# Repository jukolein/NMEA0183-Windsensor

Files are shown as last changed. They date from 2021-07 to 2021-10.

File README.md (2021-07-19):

# NMEA0183-Windsensor
A DIY-Windsensor capable of transmitting NMEA0813-sentences both wirelessly and over serial, based on an ESP8266. Build completely without custom turned parts.

sensor_komplett

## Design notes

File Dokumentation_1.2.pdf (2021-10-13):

# Windsensor III

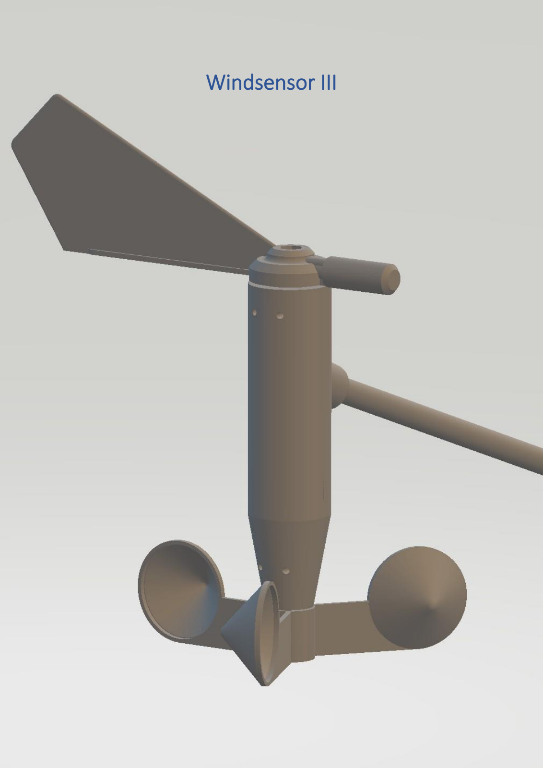
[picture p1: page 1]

## Inhaltsverzeichnis

### 1) Vorbemerkungen

Bei dem Windsensor III handelt es sich um einen einfach nachbaubaren Windsensor, der aus 3D-druckbaren Teilen und gut erhältlichen Standartkomponenten besteht. Durch den Verzicht auf Drehteile und eine einfach bedien- und anpassbare Software, an welcher keine Änderungen im Programmcode für die Integration in das eigene System benötigt werden, soll es möglichst vielen Interessierten ermöglicht werden, ihn nachzubauen.

Der Windsensor ist in der Lage Windrichtung und Windgeschwindigkeit zu messen und diese als NMEA0813-Datagramme auszugeben. Diese können danach entweder direkt über eine eigene grafische Oberfläche, welche zwar vom Windsensor bereitgestellt, jedoch vollständig auf dem Client verarbeitet wird, angezeigt oder an andere Geräte weitergegeben werden.

Diese Weitergaben kann entweder seriell, per UDP-Broadcast oder per TCP-Server geschehen. Hierfür gibt es zwei verschiedene Firmware-Versionen, eine für TCP und eine für UDP. Beide erzeugen auch immer die serielle Ausgabe.

In Ergänzung zu dieser Anleitung gibt es ein YouTube-Video, das die wichtigsten Punkte des Zusammenbaus des Windsensors noch einmal erklärt: https://www.youtube.com/watch?v=HD0CSuoLhfY

Die Firmware des Windsensors kann drahtlos aktualisiert werden, entweder über den WiFiManager oder über die OTA-Update-Funktion der Arduino-IDE

Das wichtigste in Kürze:

- Punkt des AS5600 muss von den Widerständen weg zeigen
- Widerstände der AS5600-Platine müssen unten sein
- Abgerundete Seite des Hallsensors muss nach unten zeigen
- Untere Header Leiste zum Flashen überbrücken
- Zur ersten Einrichtung mit dem WLAN „Windsensor“ verbinden, dann auf „192.168.4.1“
- Port 8080 für TCP und UDP
- „Windsensor_AP“ unter „192.168.4.1“ für Standalone

## 2) Stückliste

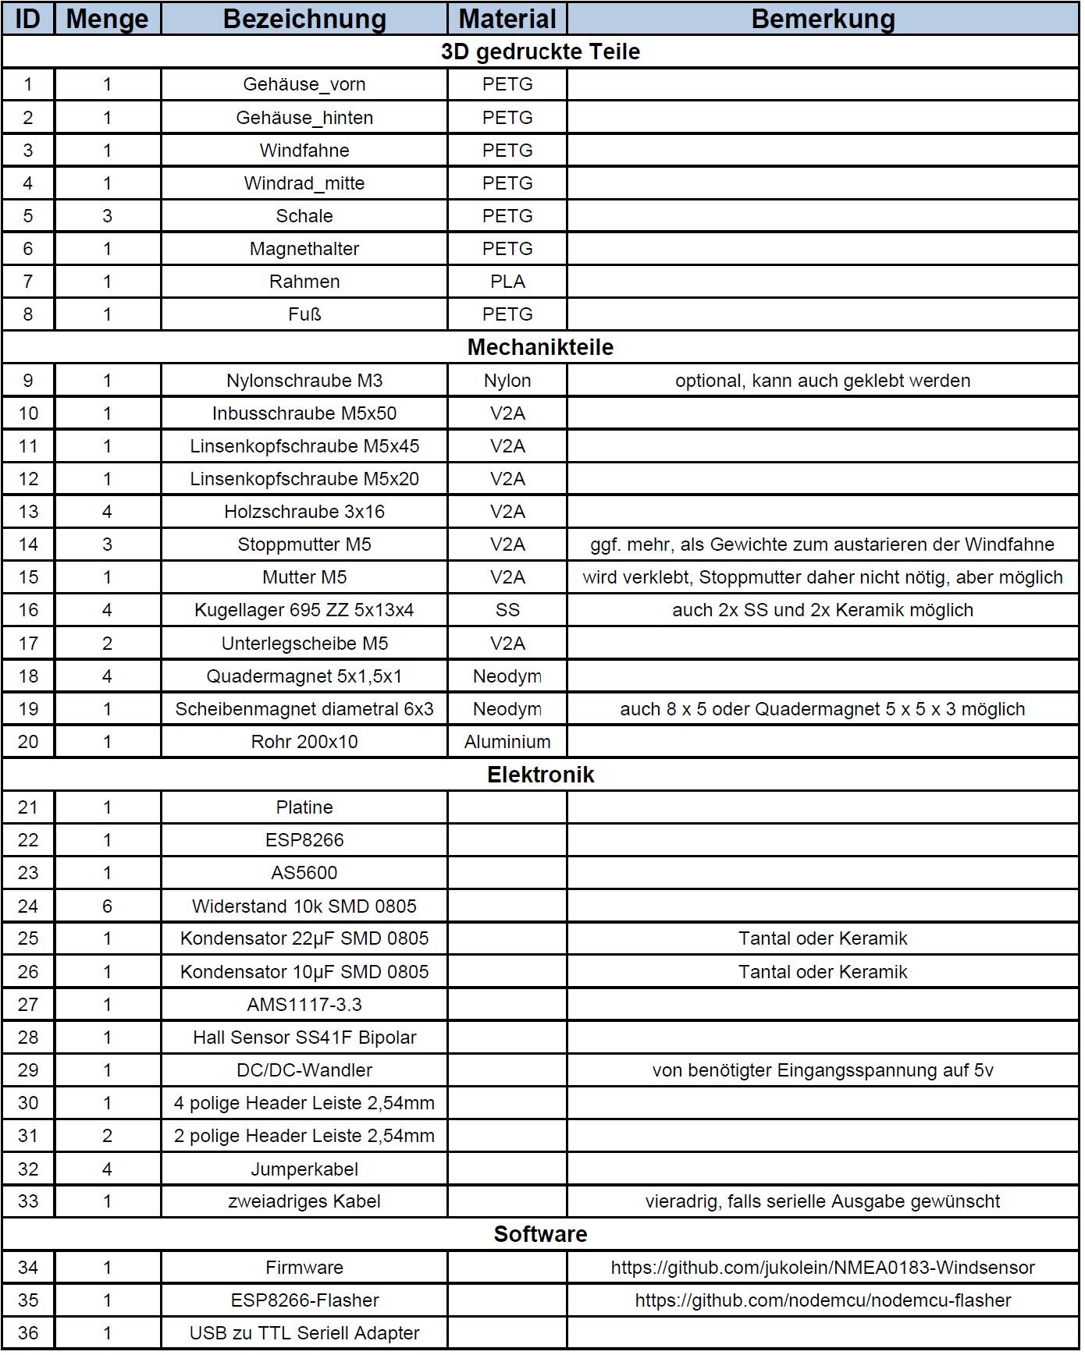
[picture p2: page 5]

## 3) Zusammenbau des Windsensors

Nachfolgend ist der Zusammenbau des Windsensors Schritt für Schritt dokumentiert. Zu Beginn eines jeden Abschnitts werden die nachfolgend benötigten Elemente aufgelistet. Die Nummern beziehen sich jeweils auf die ID der Stückliste.

### 3.1) Prüfen auf Vollständigkeit

In der nachfolgenden Abbildung fehlen der Fuß (8), die Nylonschraube (9), die Holzschrauben (13), das Alurohr (20), die elektronischen Bauteile 23 bis 26, der DC/DC-Wandler (29), die Kabel (32, 33) sowie der komplette Abschnitt Software (34 bis 36).

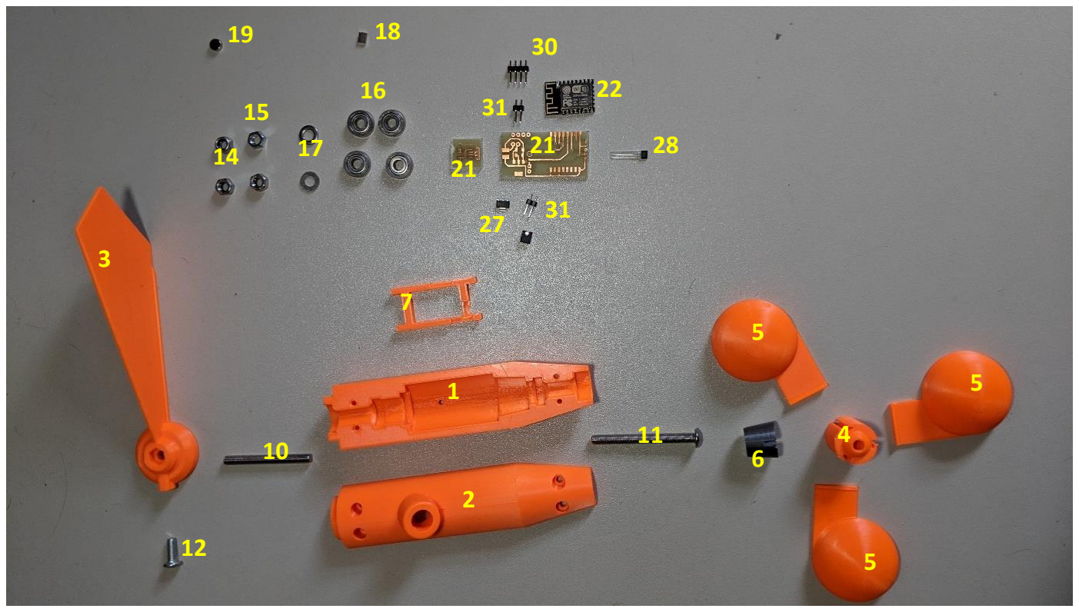
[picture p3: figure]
ine Formel ein

### 3.2) Vorbereiten des Gehäuses

Benötigte Teile: 1, 2

Um einen idealen Sitz der Kugellager zu gewährleisten ist es unter Umständen erforderlich, die Einlassungen für die Kugellager etwas nachzuarbeiten. Hierfür eignet sich etwa ein Schlitz-Schraubendreher.

### 3.3) Einkleben der Kugellager

Benötigte Teile: 1, 16

Dieser Punkt ist der wichtigste des gesamten Zusammenbaus. Sitzen die Kugellager auch nur leicht verkantet hat dies erhebliche Auswirkungen auf die Leichtgängigkeit und damit auch auf die Genauigkeit des Sensors. Es bietet sich an, die Kugellager in die obere Gehäusehälfte (1) einzukleben.

Zum Ausrichten kann die Imbus- oder Linsenkopfschraube (11/12) verwendet werden. Die Kugellager sitzen ideal, wenn die Schraube in vertikaler Position durch beide Kugellager hindurchfallen kann.

Sind die Kugellager richtig ausgerichtet, werden sie eingeklebt. Dies sollte bevorzugt mit einem restelastischen Kleber geschehen.

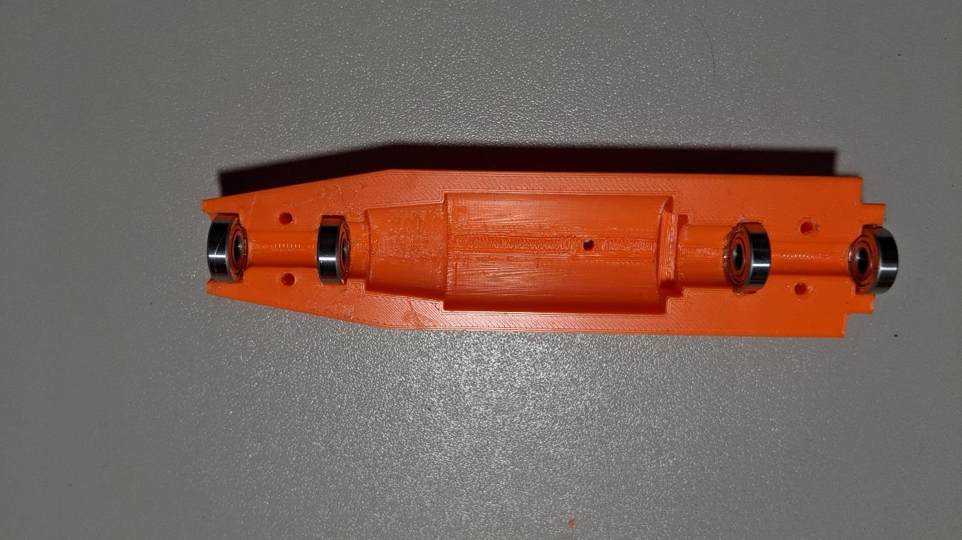
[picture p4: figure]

### 3.4) Vorbereiten des Magnethalters

Benötigte Teile: 6, 11, 14, 17

Die benötigten Teile werden wie folgt verbunden:

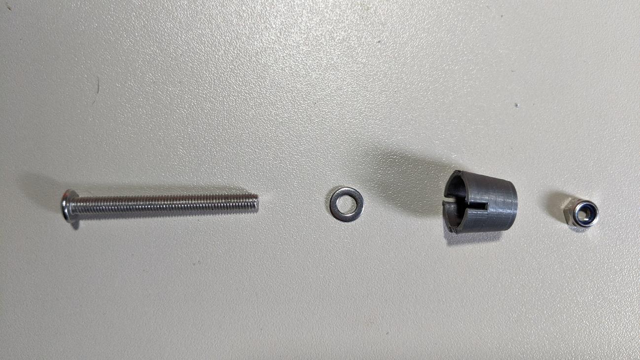
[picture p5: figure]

Die schmalere Seite der Stoppmutter muss hierbei vom Magnethalter weg zeigen.

### 3.5) Einbau der Schalen

Benötigte Teile: Alle aus Schritt 3) und 4), dazu 4, 5, 14

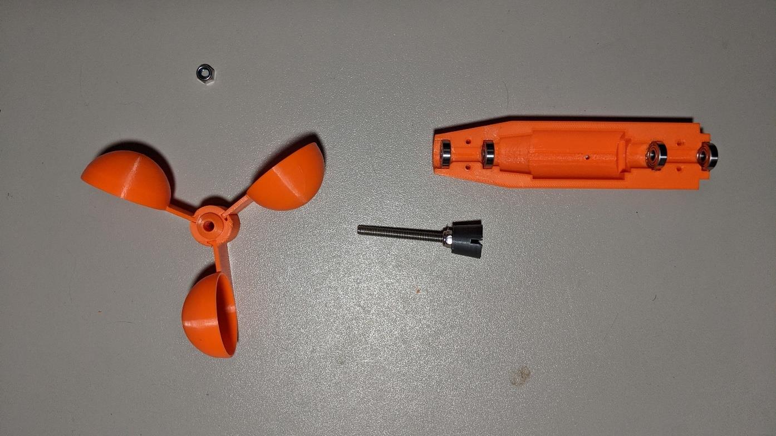
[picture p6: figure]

Zuerst die drei Schalen mit dem Windrad_mitte verbinden und mit Kleber sichern, selbst wenn sich die Teile beim Zusammenbau nur sehr schwer zusammenstecken lassen.

Anschließend den vorbereiteten Magnethalter vorsichtig durch die unteren Kugellager (die Seite, auf der sich das Gehäuse verjüngt) führen, das zusammengesteckte Windrad mit der Verjüngung in Richtung Gehäuse aufstecken und mit einer Stoppmutter sichern.

Auf freie Drehbarkeit des Magnethalters achten, besonders dann, wenn das Gehäuse mit dem zweiten Gehäuseteil geschlossen wird.

Ist die freie Drehbarkeit gewährleistet, kann die Schraube soweit angezogen werden, dass das Windrad nur noch minimales Spiel hat.

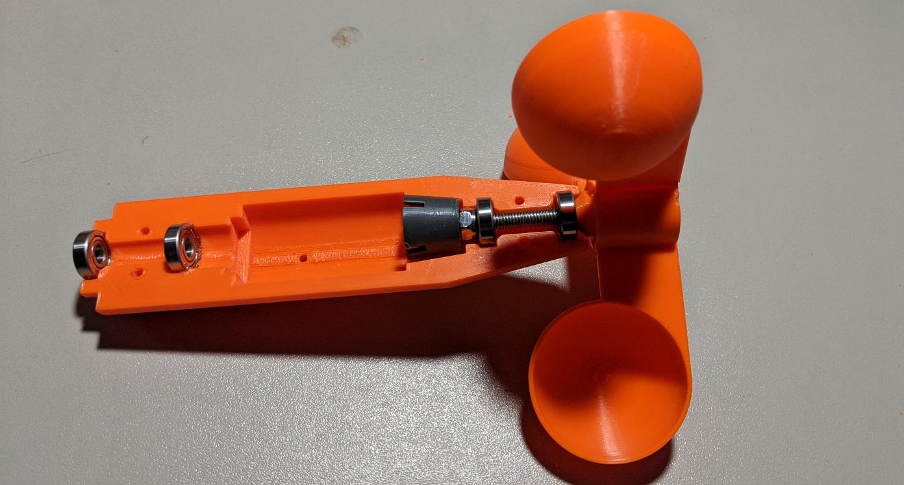
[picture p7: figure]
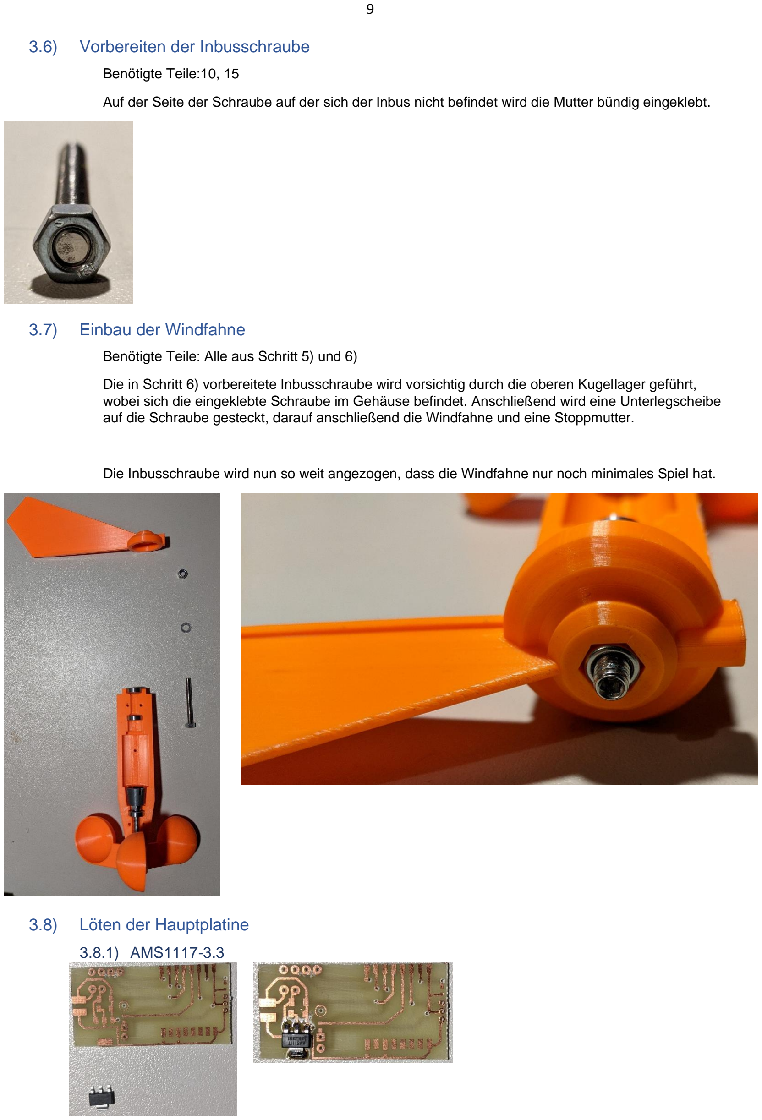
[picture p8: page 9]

### 3.6) Vorbereiten der Inbusschraube

Benötigte Teile:10, 15

Auf der Seite der Schraube auf der sich der Inbus nicht befindet wird die Mutter bündig eingeklebt.

### 3.7) Einbau der Windfahne

Benötigte Teile: Alle aus Schritt 5) und 6)

Die in Schritt 6) vorbereitete Inbusschraube wird vorsichtig durch die oberen Kugellager geführt, wobei sich die eingeklebte Schraube im Gehäuse befindet. Anschließend wird eine Unterlegscheibe auf die Schraube gesteckt, darauf anschließend die Windfahne und eine Stoppmutter.

Die Inbusschraube wird nun so weit angezogen, dass die Windfahne nur noch minimales Spiel hat.

### 3.8) Löten der Hauptplatine

3.8.1) AMS1117-3.3

3.8.2) Kondensatoren

Der 22 µF-Kondensator (25) befindet sich näher am AMS1117

3.8.3) ESP8266
3.8.4) Widerstände
3.8.5) Header Leisten
3.8.6) SS41F

Der bipolare Hallsensor muss mit der abgerundeten Seite nach unten eingesetzt werden.

### 3.8.7) Einpassen des Hallsensors

Die Füße des Hallsensors sind zu lang und müssen eingekürzt werden. Der abgerundete Teil des Sensors muss so positioniert sein, dass die Magneten des Magnethalters bei ihrer Umdrehung möglichst nah daran vorbei drehen. Der Sensor sollt somit im Besonderen nicht zu tief im Magnethalter positioniert werden.

### 3.9) Löten der AS5600-Platine

3.9.1) AS5600

Der Punkt auf dem AS5600 muss sich in der Ecke befinden, in der die zwei Kontaktflächen der Füßchen verbunden sind. Sprich: Gegenüber der zwei Widerstände, die im nächsten Schritt angelötet werden

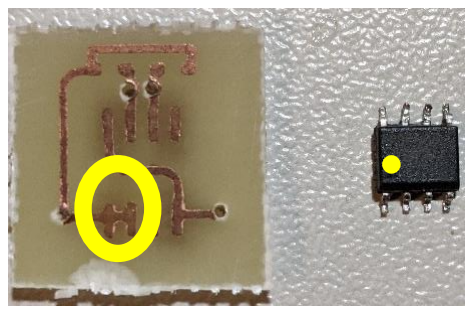
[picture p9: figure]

3.9.2) Widerstände
3.10) Verbinden der Platinen

Die kleine Platine wird mittig rechtwinklig auf die größere gelegt und beide Platinen mit Lötzinn so verbunden, dass jede der vier Lötflächen der großen Platine (zwei oben und zwei unten) mit genau einer Lötfläche der kleinen Platine kontakt hat. Beim Verbinden der beiden Platinen ist darauf zu achten, dass sich die beiden Widerstände der AS5600-Platine unterhalb der Hauptplatine befinden.

### 3.11) Einsetzen der Platine

Benötigte Teile: Alle aus Schritt 1.7) und 1.9), dazu 7

Um sicherzustellen, dass sich der AS5600 genau mittig zur Inbusschraube der Windfahne befindet, wird unter die fertige Platine ein Rahmen eingesetzt.

Anschließend wir der Hallsensor vorsichtig in den Magnethalter eingeführt und die Platine ausgerichtet

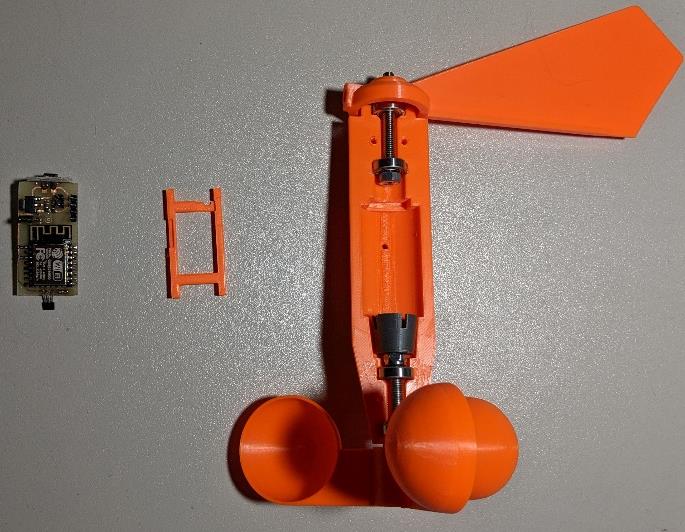
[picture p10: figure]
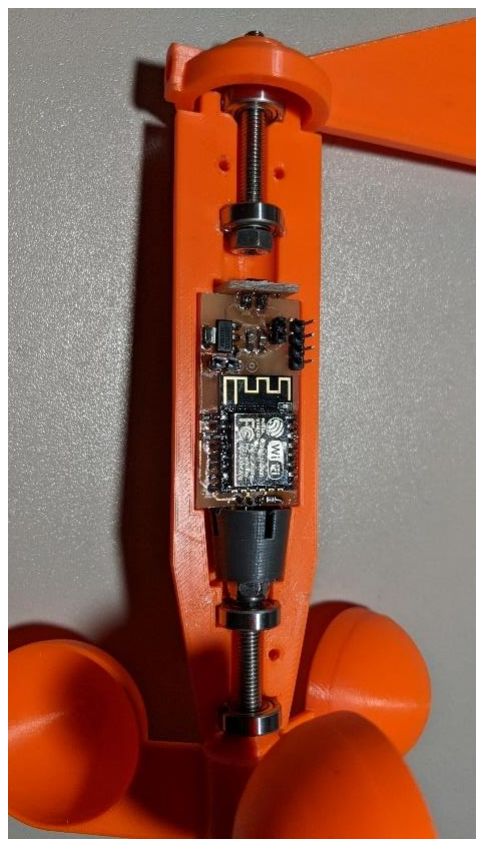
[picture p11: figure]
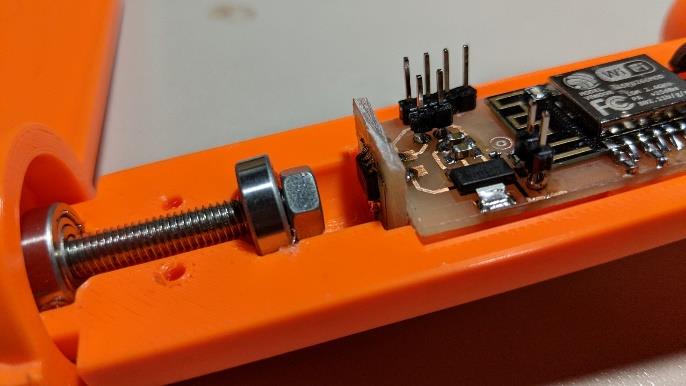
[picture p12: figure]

Ist die Platine fertig ausgerichtet, so kann sie entweder mit einer Nylonschraube (9) oder durch Kleber fixiert werden.

### 3.12) Einsetzen der Magnete

3.12.1) Scheibenmagnet

Benötigte Teile: Alle aus Schritt 1.11), dazu 18, 19

Der diametrale Scheibenmagnet wird nun mit einer Pinzette so auf die verklebte Mutter der Inbusschraube platziert, dass sie genau mittig sitzt. Ein Einkleben ist in der Regel nicht erforderlich.

3.12.2) Quadermagnete

Beim Einsetzen der Quadermagnete ist darauf zu achten, dass sich jeweils gegenüberliegenden Magneten dieselbe Polarität nach innen/außen besitzen. Dadurch wird sichergestellt, dass der Hallsensor bei der Annäherung jedes Magneten einen Wechsel im Bezug auf seinen vorherigen Zustand erkennt. Die Magnete sind anschließend durch Kleber zu sichern.

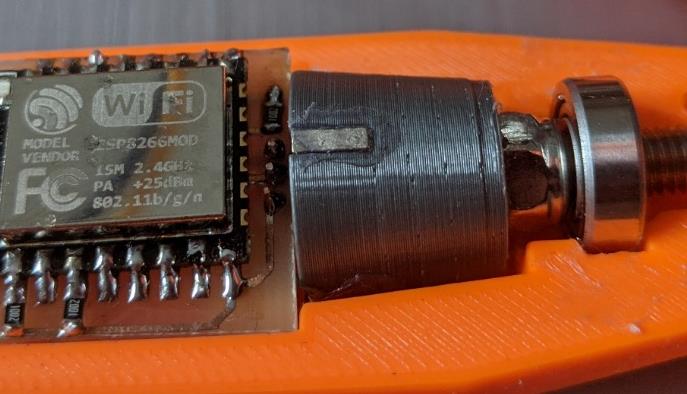
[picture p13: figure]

### 3.13) Aufspielen der Firmware

Bevor das Gehäuse verschlossen wird sollte die Firmware aufgespielt und getestet werden. Details dazu finden sich im separaten Kapitel „Aufspielen der Firmware“. Erst, wenn die Firmware erfolgreich aufgespielt und getestet wurde, sollte das Gehäuse geschlossen werden.

### 3.14) Vorbereitungen zum Schließen des Gehäuses

Benötigte Teile: Alle aus 1.12), dazu 2, 20, 33

Wurden in Abschnitt 1.8.5) die Header Leisten aufgelötet, so müssen diese nun gebogen werden, da sie anderenfalls an der Rückseite des Gehäuses anstoßen würden.

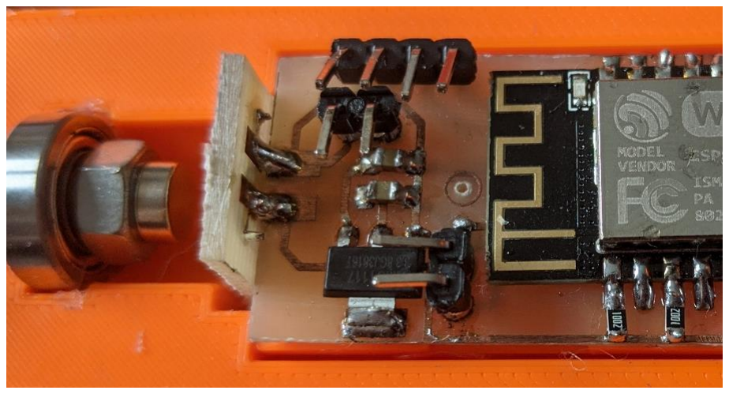
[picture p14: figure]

Das zweiadrige Kabel wird zuerst durch das Rohr und anschließend durch die Öffnung im Gehäuse_hinten geführt, bevor es mit den Pins verbunden wird.

Für den WLAN-Betrieb des Windsensors werden lediglich die ersten beiden Pins der 4er Header Leiste, beziehungsweise die darunter liegende 2er Header Leiste benötigt.

Der äußere Pin ist die Masse, der andere +5V.

### 3.15) Schließen des Gehäuses

Benötigte Teile: Alle aus 1.14), dazu 13.

Nun sollte es möglich sein, Gehäuse_hinten auf Gehäuse_vorn lege, ohne dass zwischen den beiden Hälften ein größerer Spalt entsteht. Hierzu wird die obere Seite von Gehäuse_hinten vorsichtig unter die Windfahne gehoben.

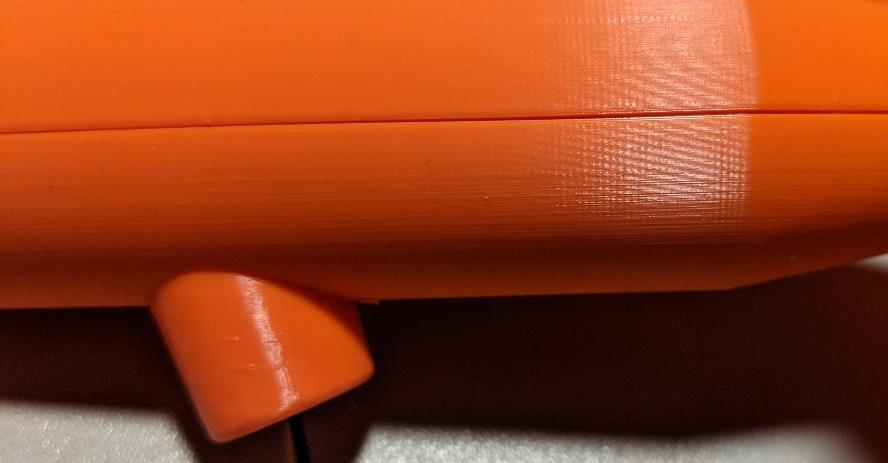
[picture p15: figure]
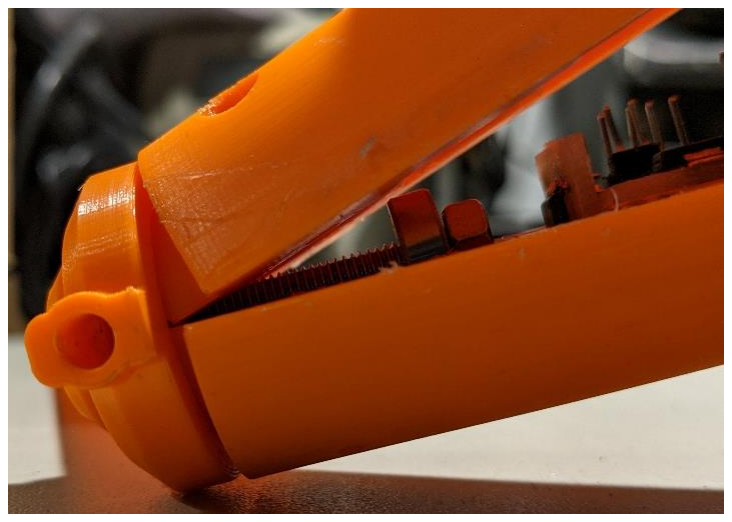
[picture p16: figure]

Es kann jedoch sein, dass sich die beiden Häften so nicht aufeinanderlegen lassen. In diesem Fall wird die Position der Inbusschraube markiert und diese wieder soweit gelockert, dass Gehäuse_hinten horizontal auf Gehäuse_vorn gelegt werden kann. Anschließend wird die Inbusschraube wieder bis zur Markierung angezogen.

Liegen beide Gehäusehälften sauber aufeinander können diese nun mit vier Schrauben fixiert werden. Danach sollte kein sichtbarer Spalt mehr zwischen den beiden Hälften erkennbar sein.

### 3.16) Austarieren der Windfahne

Benötigte Teile: Alle aus 1.15), dazu 12, 14

Um eine optimale Leichtgängigkeit der Windfahne zu erreichen, muss diese austariert werden. Dies kann durch eine Schraube geschehen, die in die Spitze der Windfahne geschraubt werden kann. Durch Muttern, die auf die Schraube geschraubt werden und deren Position verändert wird, lässt sich die Fahne sehr genau tarieren.

### 3.17) Abschlussprüfung

Alle für den Betrieb des Windsensors relevanten Schritte sind nun erfolgt. Der Windsensorsollte nun etwa wie folgt aussehen:

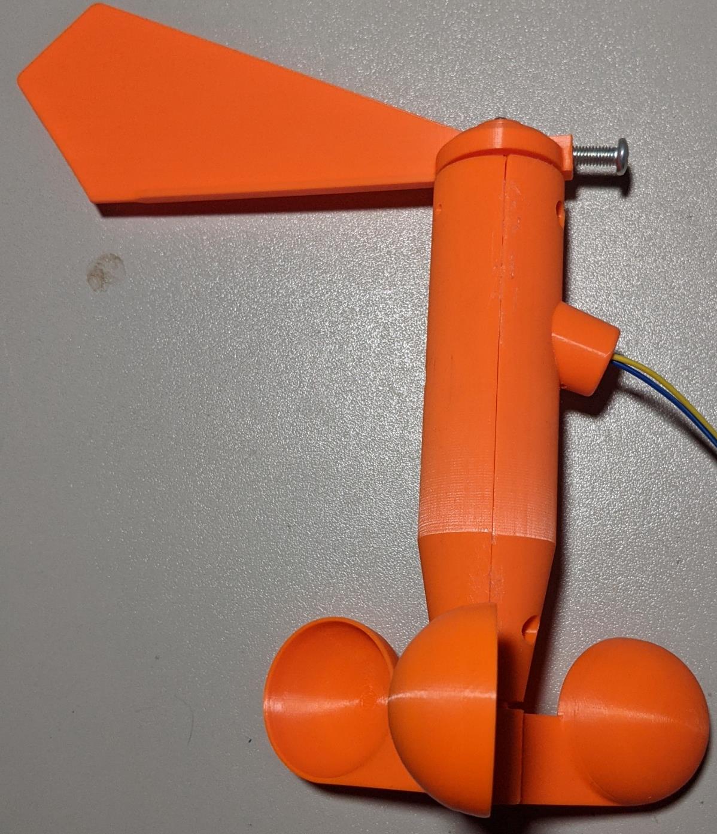
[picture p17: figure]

Besonderes Augenmerk ist hierbei auf die Leichtgängigkeit des Windrads, das sichere Erkennen jeder Magnetumdrehung durch den Hallsensor und eine austarierte Windfahne zu legen.

### 3.18) Versiegelung

Nach erfolgreicher Abschlussprüfung muss das Gehäuse im letzten Schritt noch für den Außeneinsatz versiegelt werden. Wurde PETG als Druckmaterial verwendet, so sollte eine Verklebung der vertikalen Stoßstellen von Gehäuse_vorn und Gehäuse_hinten ausreichend sein. Hierzu sollte ein restelastischer Kleber verwendet werden, etwa derselbe, der auch zum Einkleben der Kugellager verwendet wurde. Eine zusätzliche Lackierung der 3D-Teile wird jedoch trotzdem empfohlen.

### 3.19) Anmerkungen

Weder das Alurohr noch der Fuß mit DC/DC-Wandler wurden betrachtet. Bei Bedarf wird dies in zukünftigen Versionen der Anleitung geändert.

## 4) Aufspielen der Firmware

### 4.1) Vorüberlegung

Grundsätzlich gibt es für das Aufspielen der Firmware zwei Möglichkeiten:

1) Die kompilierten Binärdatei mittels NodeMCU-Flasher aufspielen (nur unter Windows)
2) Den Programmcode über die Arduino-IDE aufspielen

Welcher Weg gewählt wird hängt hauptsächlich davon ab, ob noch Änderungen am Programmcode vorgenommen werden sollen. Ist dies der Fall, so ist die Verwendung der Arduino-IDE unumgänglich. Die Vorbereitung der IDE wird im folgenden Kapitel näher betrachtet. Ist die IDE erst fertig eingerichtet, so kann das Aufspielen ganz einfach über den entsprechenden „Hochladen“-Knopf erfolgen. Hier ist jedoch auf die richtigen Einstellungen des Boards zu achten, welche ebenfalls im nächsten Kapitel näher betrachtet werden.

Sind keine Änderungen am Code gewünscht, so empfiehlt sich die Variante 1) über den NodeMCU-Flasher. Dies geht schneller und es muss auf weniger Einstellungen geachtet werden.

Jedoch gibt es den NodeMCU-Flasher aktuell nur für Windows.

### 4.2) Vorbereitung des ESP8266

Ungeachtet dessen für welchen Weg man sich entscheidet muss der ESP8266 für das Aufspielen der Firmware vorbereitet und mit dem USB-TTL-Wandler verbunden werden.

4.2.1) ESP8266

Es empfiehlt sich, den ESP8266 auf der bereits komplett bestückten Platine zu flashen, da diese den Vorbereitungsaufwand minimiert. Befindet sich der ESP8266 nämlich bereits auf der Platine, so müssen lediglich die beiden Pins der unteren Header Leiste miteinander verbunden werden, etwa durch eine Brücke. Dies stellt eine Verbindung zwischen GPIO-Pin 0 und Masse her, was den ESP8266 bei Stromzufuhr in den Flash-Modus versetzt.

4.2.2) Verbindung mit dem USB-TTL-Wandler

Ein weiterer Vorteil des Flashens auf der Platine ist es, dass die meisten USB-TTL-Wandler zu schwach sind, um den ESP8266 auf 3.3V zu versorgen. Dank des AMS1117-3.3 ist es jedoch möglich, den Chip mit 5V zu versorgen.

Die Verkabelung wird wie folgt vorgenommen:

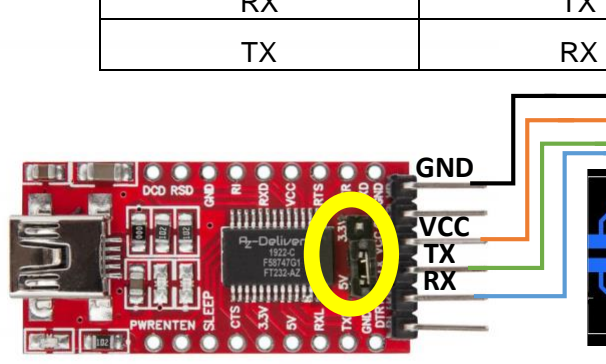
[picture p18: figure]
GND; VCC TX RX

USB-TTL-Wandler | Platine
5V | 5V
Masse | Masse
RX | TX

Zu beachten sind hierbei besonders die Brücke zu 5V auf dem USB-TTL-Wandler (gelbes Oval) sowie die Brücke zwischen den beiden unten Pins auf der Windsensor-Platine (gelbes Rechteck).

Es empfiehlt sich, die VCC-Verbindung als letzte herzustellen.

Der ESP8266 ist nun bereit mittels USB-TTL-Wandler eine neue Firmware aufgespielt zu bekommen.

Nachfolgend wird dies unter Verwendung des NodeMCU-Flashers näher beschrieben. Im Kapitel „Nutzung der Arduino-IDE“ wird das Flashen des noch nicht kompilierten Programmcodes mittels IDE erklärt.

### 4.3) Herunterladen des NodeMCU-Flashers

Der NodeMCU-Flasher kann über folgende URL heruntergeladen werden: https://github.com/nodemcu/nodemcu-flasher

### 4.4) Herunterladen der aktuellen Firmware

Die aktuelle Firmware kann, ebenfalls über GitHub, über folgenden Link bezogen werden: https://github.com/jukolein/NMEA0183-Windsensor

Die herunterzuladende Datei muss auf „.generic.bin“ enden.

### 4.5) Aufspielen der aktuellen Firmware

Es muss nichts installiert werden, es genügt die .exe zu starten.

Anschließend kontrollieren, dass unter „Advanced“ folgendes eingestellt ist, danach unter „Config“ die soeben heruntergeladene BIN-Dateien auswählen.

Unter „Operation“ den korrekten COM- Port für den USB-TTTL-Wandler auswählen und auf „Flash“ klicken.

Ein grüner Haken in der unteren rechten Ecke zeigt den Erfolg des Aufspielens an.

## 5) Nutzung der Arduino-IDE

### 5.1) Den Boardmanager für den ESP8266 hinzufügen

Hierfür muss unter „Datei → Voreinstellungen → zusätzliche Boardverwalter-URLs“ folgende URL eingegeben werden: http://arduino.esp8266.com/stable/package_esp8266com_index.json

Anschließend mit „OK“ bestätigen.

### 5.2) Die ESP8266-Boards über den Boardmanager hinzufügen

Öffnet man nun unter „Werkzeuge → Board → Boardverwalter“ den Boardverwalter und gibt oben in die Suchleiste „esp8266“ ein, erscheint folgender Eintrag:

Achtung: Es muss mindestens Version 3.0 ausgewählt werden. Die Firmware ist unter älteren Versionen nicht lauffähig.

### 5.3) Korrektes Board wählen

Unter „Werkzeuge → Board → ESP8266 Boards (3.X.X)“ nun

„Generic ESP8266 Module“ auswählen

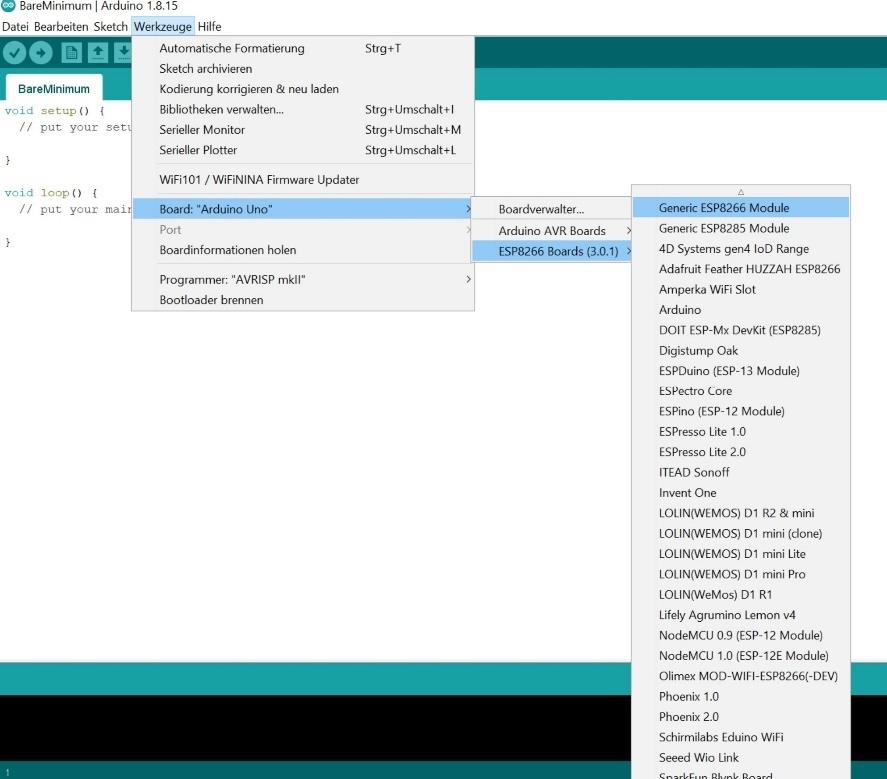
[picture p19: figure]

### 5.4) Die benötigten Bibliotheken herunterladen

Es werden zwei zusätzliche Bibliotheken verwendet: „WiFiManager“ und „AS5600“.

Um diese hinzuzufügen, gibt es zwei Möglichkeiten:

1) Die Bibliotheken werden direkt über die entsprechenden GitHub-Repos bezogen. Die Links dafür lauten wie folgt:
- WiFiManager: https://github.com/tzapu/WiFiManager
- AS5600: https://github.com/Seeed-Studio/Seeed_Arduino_AS5600
2) Es werden die im GitHub-Repo des Windsensors enthaltenen Bibliotheken verwendet. Dieser Weg wird im Folgenden gezeigt.

### 5.5) Das GitHub-Repo herunterladen

Die Dateien können bequem über den Browser heruntergeladen werden. Hierfür wird erst auf „Code“ geklickt und anschließend das Repo durch einen Klick auf „Download ZIP“ heruntergeladen. Die ZIP-Datei muss danach auf dem Rechner entpackt werden.

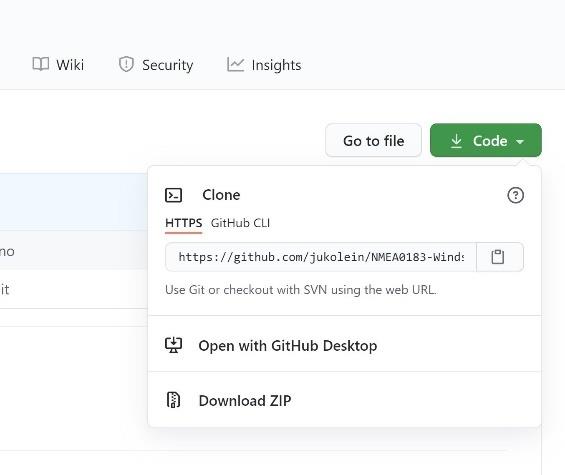
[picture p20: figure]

### 5.6) Die benötigten Bibliotheken hinzufügen

Über „Sketch → Bibliothek einbinden → .ZIP-Bibliothek hinzufügen“ können nun die benötigten Bibliotheken eingebunden werden.

Diese befinden sich in „Firmware → Libraries“. Die darin enthaltenen .ZIP-Dateien müssen nicht entpackt werden, sondern werden so direkt in die Arduino-IDE importiert.

Anschließend sollten diese unter „Sketch → Bibliotheken einbinden“ im Abschnitt „Beigetragene Bibliotheken“ aufgelistet sein.

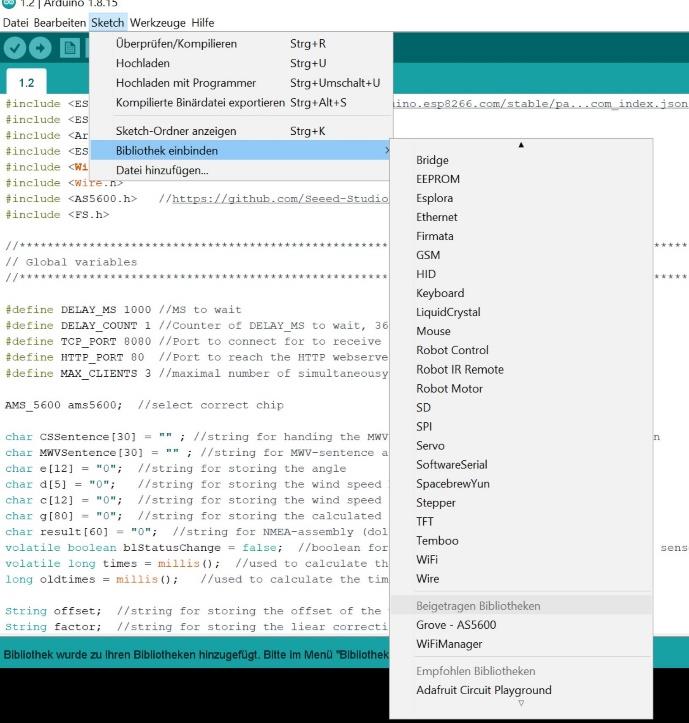
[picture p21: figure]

Damit ist die Arduino IDE nun fertig vorbereitet und es können gegebenenfalls Änderungen am Code vorgenommen werden. Durch Lade der unveränderten Firmware in die Arduino-IDE und Klickens auf „Überprüfen“ (oben links) lässt sich feststellen, ob die Einrichtung erfolgreich war.

### 5.7) Vorbereitungen zum Flashen der Firmware

Um sicherzustellen, dass die Firmware erfolgreich auf den ESP8266 überspielt werden kann und auf diesem auch lauffähig ist, müssen folgende Einstellungen unter „Werkzeuge“ vorgenommen werden:

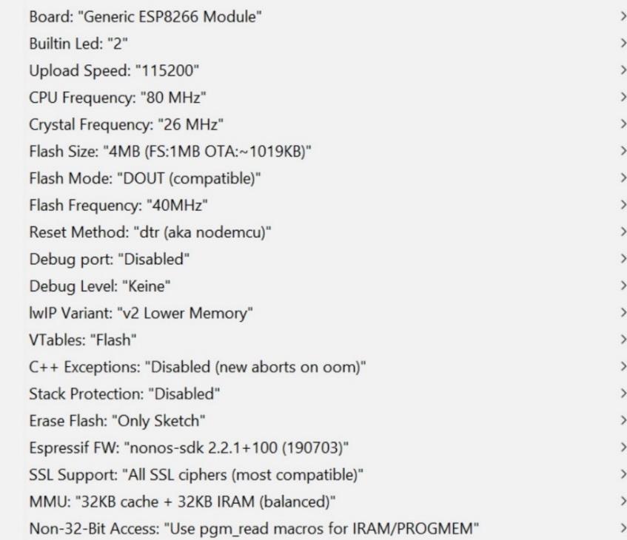
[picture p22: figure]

Sind die Einstellungen entsprechend vorgenommen worden und wurde der ESP8266 richtig mit dem USB-TTL-Wandler verbunden (siehe Abschnitt 4.2), kann die Firmware aufgespielt werden.

## 6) Einrichtung

Beim ersten Start nach dem Aufspielen der Firmware erstellt der ESP32 einen Access Point mit dem Namen „Windsensor“.

Nach erfolgreicher Verbindung mit diesem Netzwerk sollte man automatisch auf „192.168.4.1“ weitergeleitet werden. Ist dies nicht der Fall, so muss die IP manuell aufgerufen werden. Wie es danach weiter geht, hängt davon ab, welcher Nutzungsmodus (Integration in ein bestehendes Netzwerk oder Standalone) geplant ist. In beiden Fällen werden die NMEA0813-Daten zusätzlich immer seriell ausgegeben.

### 6.1) TCP

Hierbei stellt der ESP32 einen TCP-Webserver bereit, von dem sich die Clients (etwa SignalK oder AVnav) die NMEA-Daten holen können.

Hierfür ist es in aller Regel erforderlich, den ESP8266 mit einem bereits bestehenden Netzwerk zu verbinden. Dies kann leicht über die grafische Oberfläche des WiFiManagers geschehen.

Durch einen Klick auf „Configure WiFi“ gelangt man zu einer Auflistung aller verfügbaren WLAN-Netzwerke, durch einen Klick auf das gewünschte Netzwerk wird dessen SSID automatisch in das dafür vorgesehene Feld eingetragen, so dass nur noch das Passwort ergänz werden muss. Durch Klicken auf „Save“ werden die Änderungen übernommen, der ESP32 startet sich neu und versucht, sich mit dem angegebenen WLAN zu verbinden. Gelingt dies nicht, so startet sich der Access Point „Windsensor“ erneut und wartet auf Eingaben.

Anschließend muss der Client (etwa SignalK oder AVnav) darauf konfiguriert werden, die NMEA0813-Daten unter der IP des ES32 auf Port 8080 zu empfangen.

### 6.2) Standalone

Der Windsensor ist auch in der Lage ohne vorhandene Netzwerke zu arbeiten und baut in diesem Fall sein eigenes WLAN-Netz auf.

Um dies zu erreichen, klickt man auf der Konfigurationsseite direkt auf „Exit“. Nach kurzer Zeit sollte nun das neue WLAN-Netzwerk „Windsensor_AP“ sichtbar sein, mit dem man sich mit dem Passwort „123456789“ verbinden kann. Der Windsensor ist von allen mit diesem Netzwerk verbundenen Geräten aus unter „192.168.4.1“ erreichbar.

Um den Sensor dauerhaft im Standalone-Modus zu halten, muss dies noch in der Einstellungsseite aktiviert werden.

### 6.3) Grafische Oberfläche

Die grafische Oberfläche des Windsensors ist sowohl unter seiner IP-Adresse als auch unter „windsensor.local“ erreichbar. Jedoch funktioniert letzteres nur unter IOS zuverlässig und ohne weiteren Einrichtungsbedarf, unter Windows nur mittels spezieller „Bonjour“-Software, unter Linux nur nach Installation von mDNS-Paketen und unter Android gar nicht.

### 6.4) Anzeige der Winddaten

Der Windsensor verfügt neben einem TCP-Server auf Port 8080, über den die NMEA0813-Telegramme ausgesendet werden, auch noch einen http-Webserver auf Port 80. Dieser dient sowohl zur grafischen Anzeige der Winddaten als auch zur Verwaltung des Sensors.

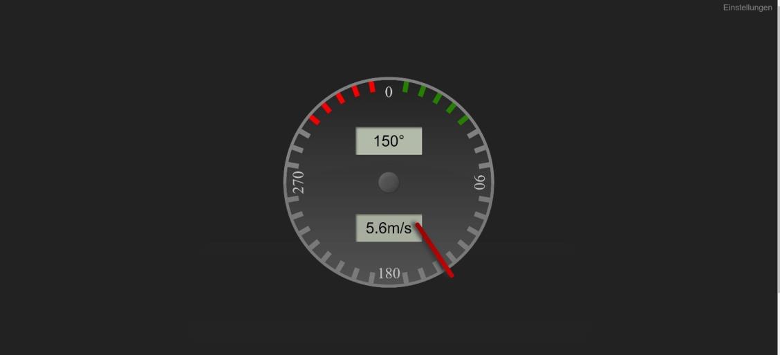
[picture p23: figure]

Angezeigt wird der scheinbare Wind in Grad sowie die aktuelle Windgeschwindigkeit in m/s.

Vielen Dank an ziegenhagel.com https://ziegenhagel.com/ für das Programmieren der Oberfläche.

Die Verarbeitung und Anzeige der Daten findet vollständig auf dem Client statt, so dass der ESP32 nicht belastet wird. Dieser stellt lediglich unter „/data“ den aktuellen NMEA0813-Satz zur Verfügung und aktualisiert ihn jedes Mal, wenn die Seite neu aufgerufen wird.

In der oberen rechten Ecke befindet sich ein Link, der auf die Einstellungsseite des Windsensors führt.

### 6.5) Einstellungsseite

Unter „/config“ besitzt der Windsensor eine Seite um Einstellungen an ihm vorzunehmen.

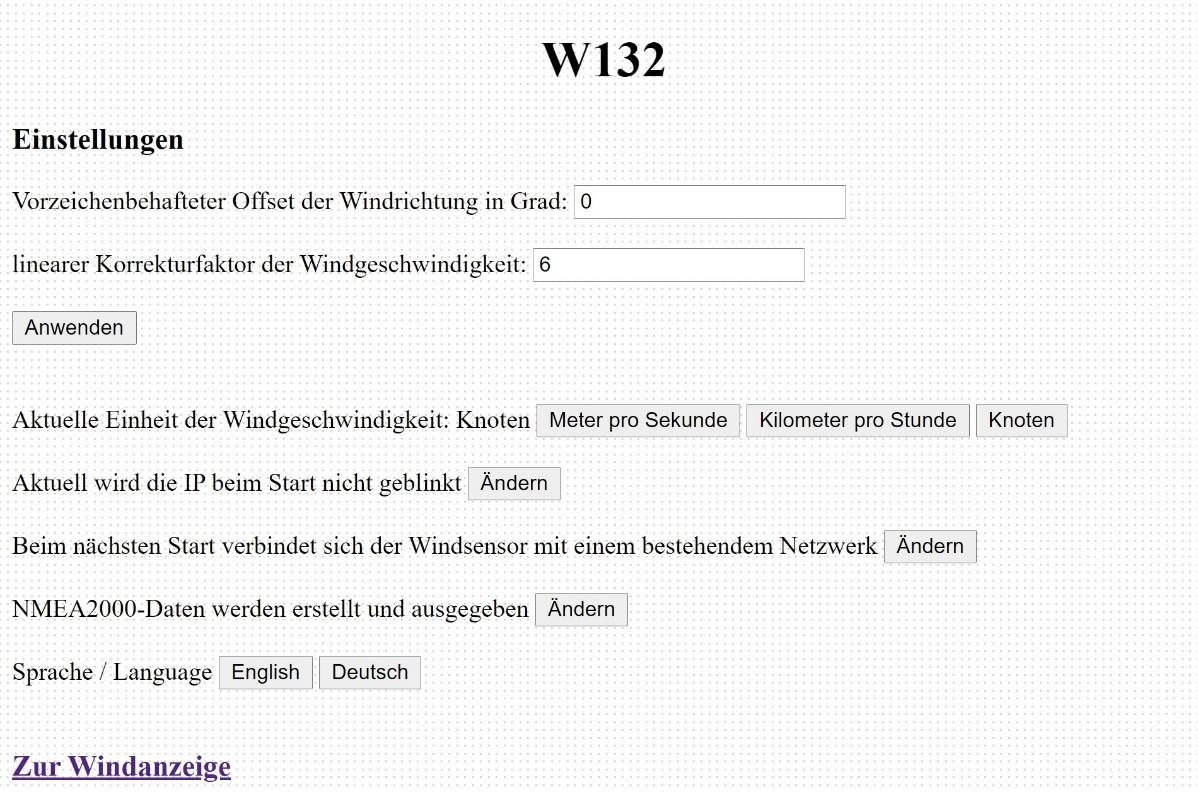
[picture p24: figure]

Alle vorgenommenen Einstellungen bleiben auch nach Neustart sowie Trennung vom Strom erhalten.

6.5.1. Offset

Unter „Vorzeichenbehafteter Offset der Windrichtung in Grad“ können ganze Zahlen mit oder ohne Vorzeichen eingegeben werden. „5“ wird dazu führen, dass immer fünf Grad auf den durch den AS5600 ermittelten Winkel aufaddiert werden, „-5“ führt zu einem Abzug von fünf Grad. Um die Änderungen anzuwenden, muss auf den Knopf „Anwenden“ geklickt werden.

6.5.2) Korrekturfaktor

Unter „linearer Korrekturfaktor der Windgeschwindigkeit“ kann eine beliebige Fließkommazahl eingegeben werden. Diese wird als Faktor zur ermittelten Windgeschwindigkeit hinzumultipliziert. Um die Änderungen anzuwenden, muss auf den Knopf „Anwenden“ geklickt werden.

6.5.3) Einheit der Windgeschwindigkeit
An dieser Stelle kann eingestellt werden, in welcher Einheit (Kilometer pro Stunde, Meter pro Sekunde oder Knoten) die Windgeschwindigkeit dargestellt werden soll.

Dies hat jedoch keine Auswirkungen auf die ausgesendeten NMEA-Datagramme, diese sind nicht veränderbar in Knoten.

6.5.4) Blinken der IP

Zwar besitzt der Windsensor einen mDNS-Server, der ihn, unabhängig von seiner IP unter „windsensor.local“ erreichbar macht, jedoch funktioniert das nur mit iOS-Geräten zuverlässig.

Um die Einrichtung des Windsensors trotzdem so einfach wie möglich zu gestalten, blinkt dieser beim Start seine ihm zugewiesene IP-Adresse ziffernweise mit der integrierten LED. Um auch Nullen darstellen zu können, wird immer einmal mehr geblinkt als der Wert der Ziffer angibt, Somit wird eine Null durch ein Blinken dargestellt, eine Eins zur zwei Blinken, eine Drei durch vier blinken etc.

Punkte zwischen den Blöcken werden durch dreimaliges kurzes Blinken schnell hintereinander signalisiert.

Das Blinken der IP verlangsamt den Startvorgang des ESP erheblich, da die gesamte IP zunächst geblinkt werden muss, bevor es weiter gehen kann. Daher ist es empfehlenswert, das Blinken der IP über die Einstellungsseite zu deaktivieren, sobald es nicht mehr benötigt wird. Dafür muss der „Ändern“-Knopf gedrückt werden. Dies sollte dazu führen, dass sich der Text von „Die IP wird beim Start geblinkt“ in „Die IP wird beim Start nicht geblinkt“ ändert.

6.5.5) Netzwerk- oder Standalone-Modus
An dieser Stelle kann eingestellt werden, ob der Windsensor beim Start versucht sich mit einem bestehenden Netzwerk zu verbinden oder ob er einen Access Point aufspannen soll.
6.5.6) NMEA 2000
Da das Erstellen der NMEA 2000-Daten sehr rechenintensiv ist, es aber auch durchaus möglich (wenn nicht gar wahrscheinlicher) ist, dass der Sensor „nur“ für NMEA 0183 verwendet wird, gibt es an dieser Stelle die Möglichkeit, die Verarbeitung von NMEA 2000 zu deaktivieren.
6.5.7) Sprache/Language
Die grafische Oberfläche des Windsensors ist sowohl auf Deutsch als auch auf Englisch verfügbar. Hier kann die Sprache umgestellt werden.

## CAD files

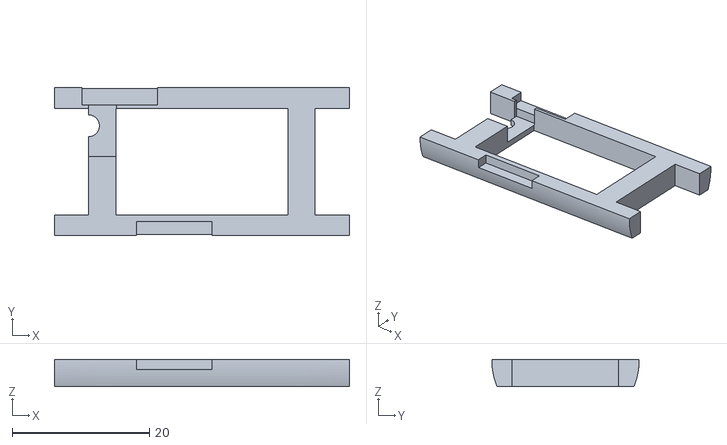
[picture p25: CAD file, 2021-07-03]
STL/Rahmen.stl
43.0 x 21.5 x 4.00

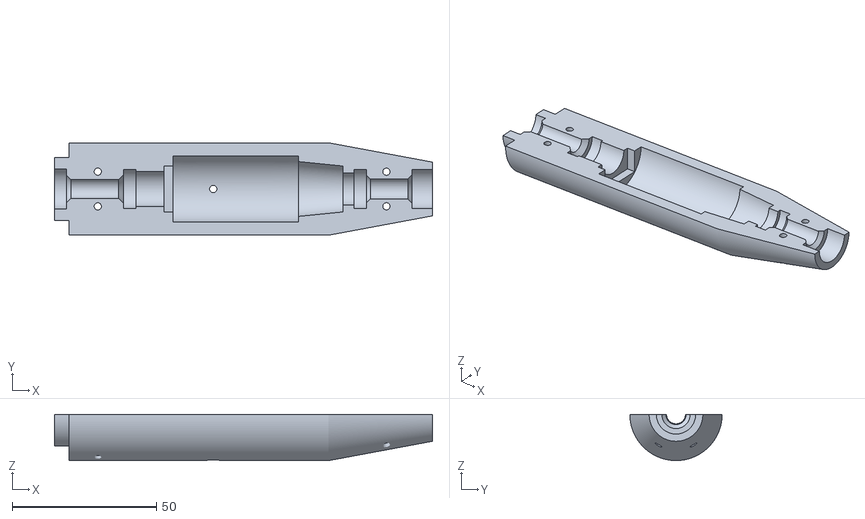
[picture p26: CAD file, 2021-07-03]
STL/Gehäuse_vorn.stl
131.0 x 32.0 x 16.0

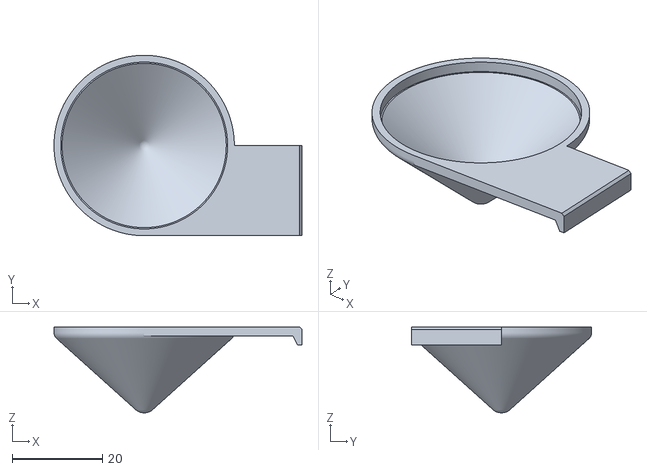
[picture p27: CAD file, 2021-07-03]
STL/Schale_spitz.stl
55.0 x 40.0 x 19.0

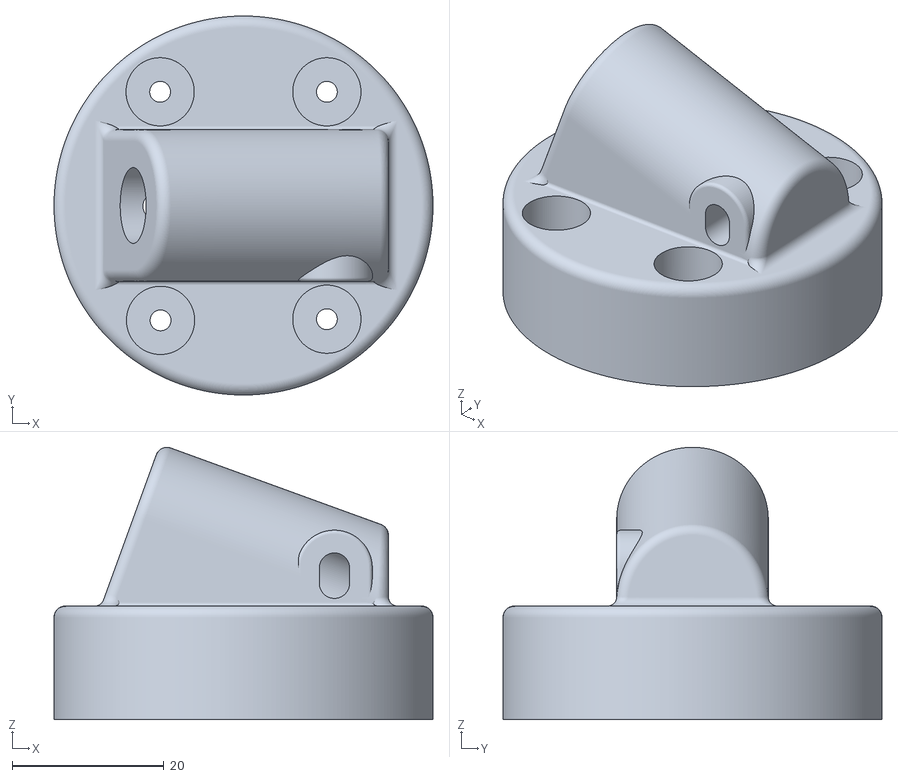
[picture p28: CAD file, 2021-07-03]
STL/Fuß.stl
50.0 x 50.0 x 35.9

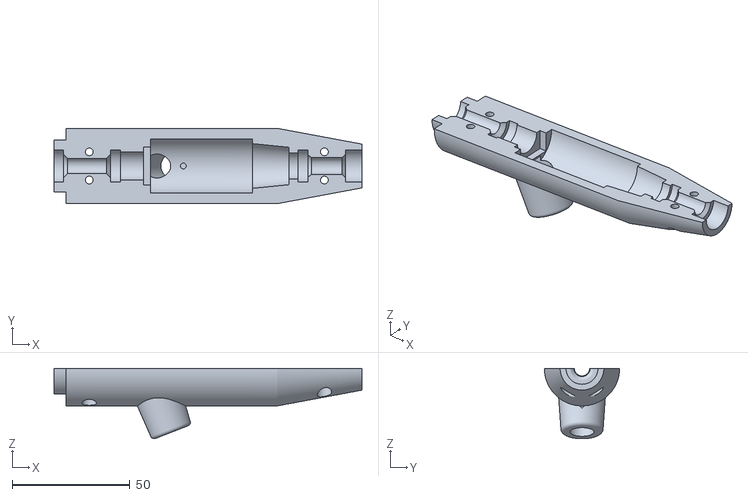
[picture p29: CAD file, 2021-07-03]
STL/Gehäuse_hinten.stl
131.0 x 32.0 x 30.0

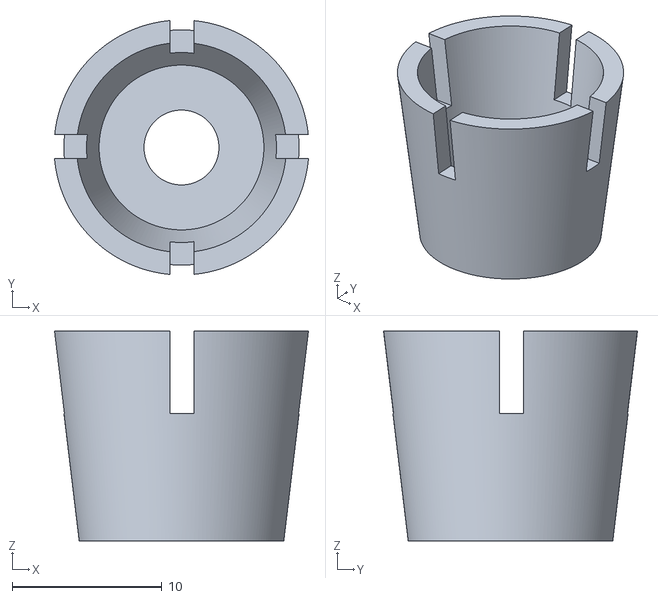
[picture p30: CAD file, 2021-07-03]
STL/Magnethalter.stl
17.0 x 17.0 x 14.0

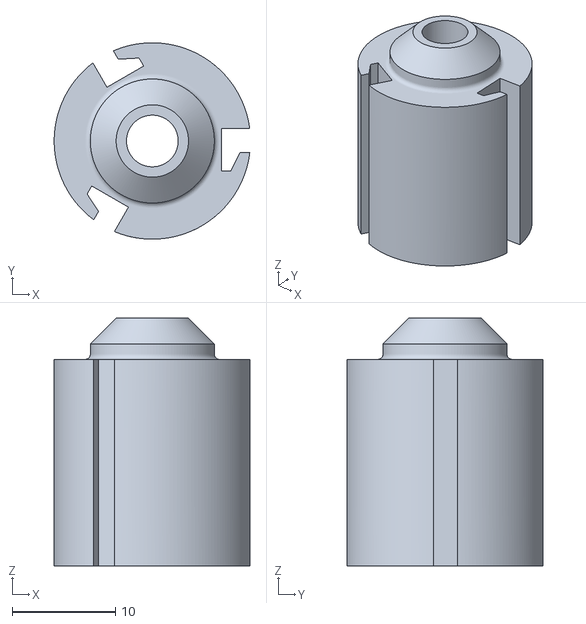
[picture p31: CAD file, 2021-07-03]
STL/Windrad_mitte.stl
18.9 x 19.0 x 24.0

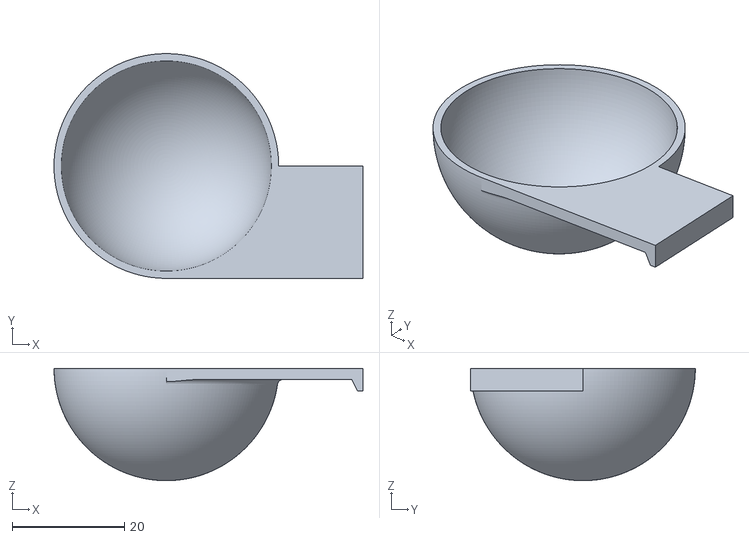
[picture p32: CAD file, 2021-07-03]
STL/Schale_rund.stl
55.0 x 40.0 x 20.0

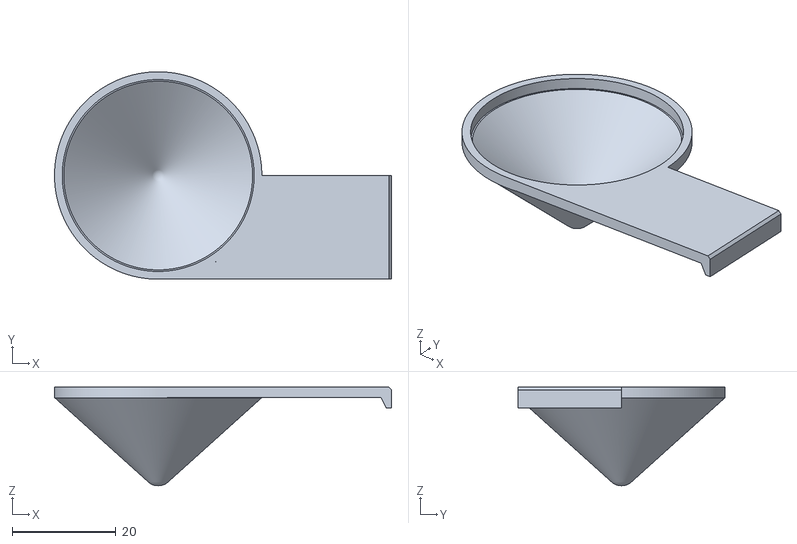
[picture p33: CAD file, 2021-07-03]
STL/Schale_spitz_lang.stl
65.0 x 40.0 x 19.0

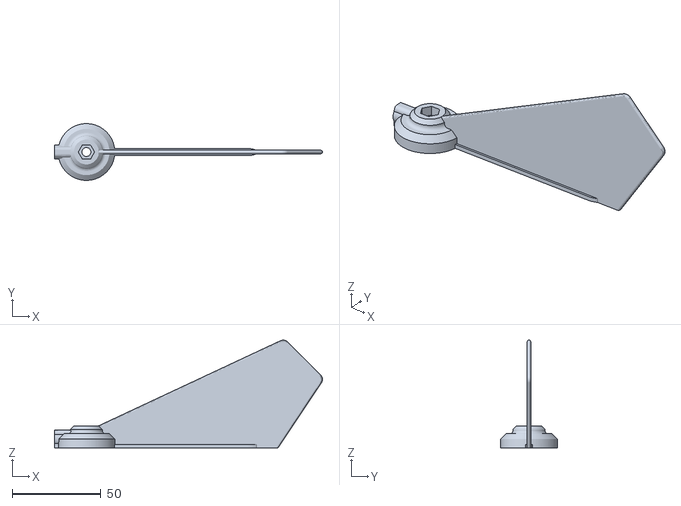
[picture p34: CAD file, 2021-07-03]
STL/Windfahne.stl
151.1 x 32.0 x 60.8

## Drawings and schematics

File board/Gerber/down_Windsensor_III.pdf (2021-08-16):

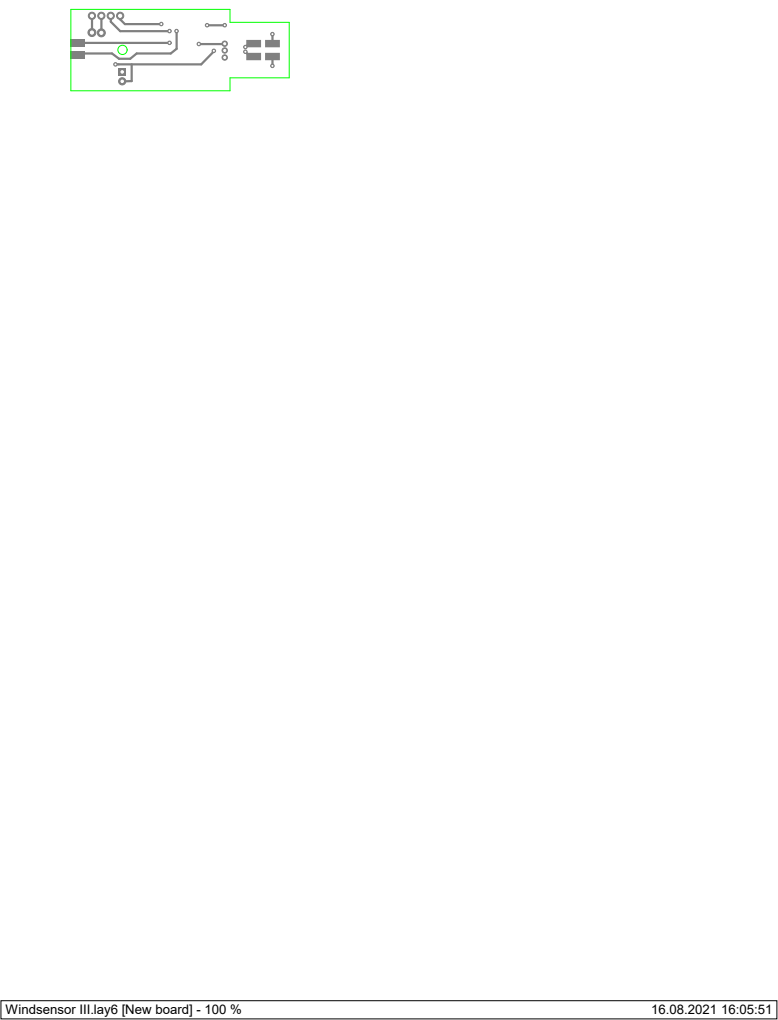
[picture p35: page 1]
Windsensor III.lay6 [New board] - 100 %

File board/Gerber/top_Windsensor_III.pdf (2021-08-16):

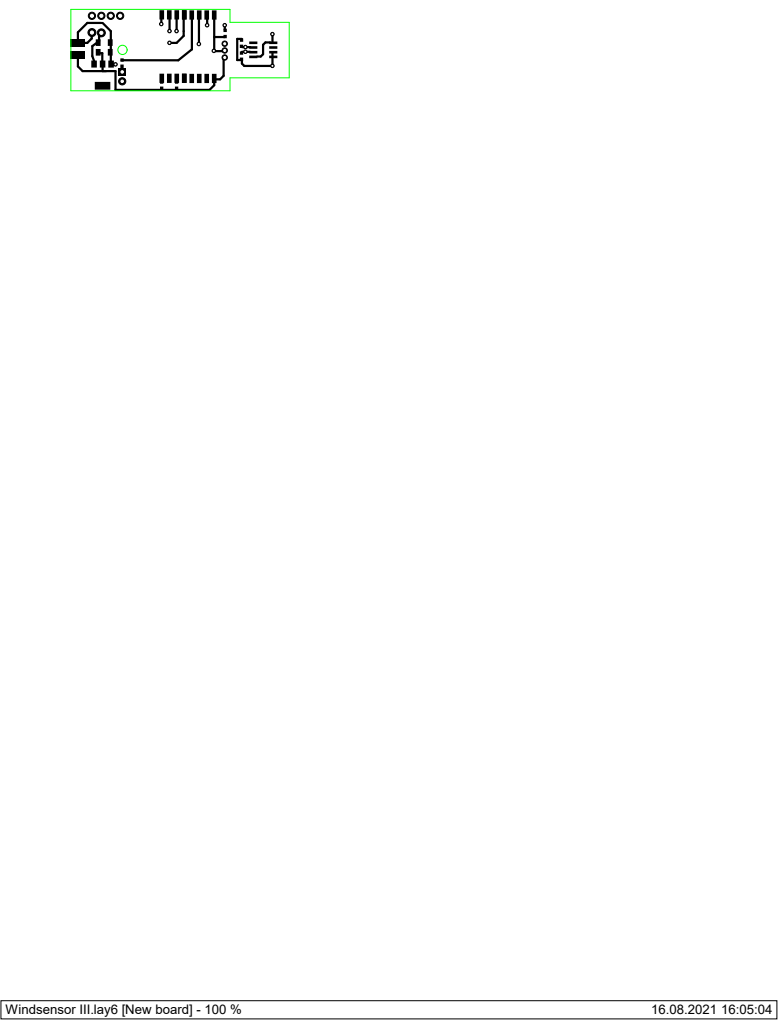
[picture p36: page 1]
Windsensor III.lay6 [New board] - 100 %

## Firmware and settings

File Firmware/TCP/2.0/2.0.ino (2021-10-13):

#ifdef ESP32 
  #define ESP32_CAN_TX_PIN GPIO_NUM_5  // Set CAN TX port to 5, must be at the very top to work, don't move down
  #define ESP32_CAN_RX_PIN GPIO_NUM_4  // Set CAN RX port to 4, must be at the very top to work, don't move down
#endif
//--------------------------------------------------------
// general and NMEA0183 includes
//--------------------------------------------------------
#include <ArduinoOTA.h>
#include <WiFiManager.h>         // https://github.com/tzapu/WiFiManager
#include <Wire.h>
#include <AS5600.h>   //https://github.com/Seeed-Studio/Seeed_Arduino_AS5600

#ifdef ESP32
  #include <WiFi.h>
  #include <ESPmDNS.h>
  #include <WebServer.h>
  #include "SPIFFS.h"
  #include <WiFi.h>
    //--------------------------------------------------------
    // NMEA2000 includes
    //--------------------------------------------------------
    #include <Preferences.h>
    #include <NMEA2000_CAN.h>  // This will automatically choose right CAN library and create suitable NMEA2000 object
    #include <N2kMessages.h>
#else
  #include <ESP8266WiFi.h> // ESP8266 library, http://arduino.esp8266.com/stable/pa...com_index.json
  #include <ESP8266mDNS.h>
  #include <ESP8266WebServer.h>
  #include <FS.h>
#endif

//******************************************************************************************************************************************************
// general and NMEA0813 variables in global scope
//******************************************************************************************************************************************************

#define DELAY_MS 1000 //MS to wait in the loop function
#define DELAY_COUNT 1 //Counter of DELAY_MS to wait, 3600 is 1 hour
#define TCP_PORT 8080 //Port to connect for to receive the NMEA sentences via TCP
#define HTTP_PORT 80  //Port to reach the HTTP webserver 
#define MAX_CLIENTS 3 //maximal number of simultaneousy connected clients

#define LED 2  //at ESP32_dev_kit, LED is at pin 2, also at the ESP8266

AMS_5600 ams5600;  //select correct chip

long WS = 0;  //stores the value of the wind speed
int Z = 0;  //stores the angle of the wind direction in degrees

char CSSentence[30] = "" ; //string for handing the MWV-sentence over to the checksum-function
char MWVSentence[30] = "" ; //string for MWV-sentence assembly (Wind Speed and Angle)
char e[12] = "0";  //string for storing the angle
char d[5] = "0";   //string for storing the wind speed before the dot
char c[12] = "0";  //string for storing the wind speed after the dot
char g[80] = "0";  //string for storing the calculated checksum as a char array
char result[60] = "0";  //string for NMEA-assembly (dollar symbol, MWV, CS)
volatile long times = millis();  //used to calculate the time between two status changes
long oldtimes = millis();   //used to calculate the time between two status changes

String offset;  //string for storing the offset of the wind angle
String factor;  //string for storing the liear correction facor of the wind speed
String blIPblink;  //string for storing if the IP is to be blinked or not. "geblinkt" equals "true", "nicht geblinkt" equals "false"
String ws_unit;  //string for storing the unit of the wind speed, like knots or meters per second, only affects the graphical display
String language;  //stirng for storing the display language
String ap;  //string for storing if sensor should run in accespoint-mode
String nmea2k;  //string for storing if NMEA2000 schould be processed and send or not

#ifdef ESP32
  //--------------------------------------------------------
  // NMEA2000 variables in global scope
  //--------------------------------------------------------

  int NodeAddress;  //stores last Node Address
  Preferences preferences;  //stores LastDeviceAddress

  const unsigned long TransmitMessages[] PROGMEM = {13030L,  //Set the information for other bus devices, which messages we support, here: wind (13030). see: https://www.nmea.org/Assets/20151026%20nmea%202000%20pgn_website_description_list.pdf
                                                    0
                                                    };
#endif
                                                  
//--------------------------------------------------------
// ESP8266 WiFi and webserver variables
//--------------------------------------------------------

WiFiServer server(TCP_PORT); //define the server port
WiFiClient clients[MAX_CLIENTS]; //Array of clients

#ifdef ESP32
  WebServer webserver(HTTP_PORT); //define the HTTP-webserver port
#else
  ESP8266WebServer webserver(HTTP_PORT); //define the HTTP-webserver port
#endif

//******************************************************************************************************************************************************
// HTML PAGES
//******************************************************************************************************************************************************

//--------------------------------------------------------
// correction_page - the HTML code for the page where
// the correction values are set
// located in PROGMEM, as it is going to be static
//--------------------------------------------------------

const char correction_page_de[] PROGMEM = R"=====(
<!DOCTYPE html>
<head>
  <meta content="text/html; charset=UTF-8" http-equiv="content-type">
<style>
  body{ 
  background-image:url("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");">
}
</style>
</head>
<html>
<body>
<h1 style="text-align: center;">Windsensor<h1>
<h3>Einstellungen</h3>

<form action="/action_page">
  Vorzeichenbehafteter Offset der Windrichtung in Grad: <input type="text" name="offset_html" value="offset_placeholder">
  <br>  <br>
  linearer Korrekturfaktor der Windgeschwindigkeit: <input type="text" name="factor_html" value="factor_placeholder">
  <br>  <br>
  <input type="submit" value="Anwenden">
</form> 
<br>  <br>
Aktuelle Einheit der Windgeschwindigkeit: ws_unit_placeholder 
   <input type="button" onclick="location.href='/meters';" value="Meter pro Sekunde" />
   <input type="button" onclick="location.href='/kilometers';" value="Kilometer pro Stunde" />
   <input type="button" onclick="location.href='/knots';" value="Knoten" />
<br>  <br>
   Aktuell wird die IP beim Start ipblink_placeholder <input type="button" onclick="location.href='/ipblink';" value="Ändern" />
<br>  <br>
   Beim nächsten Start ap_placeholder <input type="button" onclick="location.href='/ap';" value="Ändern" />
<br>  <br>
   nmea2k_placeholder
   
   Sprache / Language
   <input type="button" onclick="location.href='/language_en';" value="English" />
   <input type="button" onclick="location.href='/language_de';" value="Deutsch" />
<br>  <br>
 <h3>  <a href='/'> Zur Windanzeige </a> </h3>

</body>
</html>
)=====";

const char correction_page_en[] PROGMEM = R"=====(
<!DOCTYPE html>
<head>
  <meta content="text/html; charset=UTF-8" http-equiv="content-type">
<style>
  body{ 
  background-image:url("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");">
}
</style>
</head>
<html>
<body>
<h1 style="text-align: center;">Windsensor<h1>
<h3>Settings</h3>
<form action="/action_page">
  signed offset of the wind direction in degrees: <input type="text" name="offset_html" value="offset_placeholder">
  <br>  <br>
  linear correction factor: <input type="text" name="factor_html" value="factor_placeholder">
  <br>  <br>
  <input type="submit" value="Apply">
</form>
<br>  <br>
current wind speed unit: ws_unit_placeholder 
   <input type="button" onclick="location.href='/meters';" value="meters per second" />
   <input type="button" onclick="location.href='/kilometers';" value="kilometres per hour" />
   <input type="button" onclick="location.href='/knots';" value="knots" />
<br>  <br>
At the next boot, the IP of the sensor will ipblink_placeholder <input type="button" onclick="location.href='/ipblink';" value="Change" />
<br>  <br>
At the next boot ap_placeholder <input type="button" onclick="location.href='/ap';" value="Change" />
<br>  <br>
   nmea2k_placeholder
   
 Language / Sprache
   <input type="button" onclick="location.href='/language_en';" value="English" />
   <input type="button" onclick="location.href='/language_de';" value="Deutsch" />
<br>  <br>
 <h3>  <a href='/'> To the graphic display </a> </h3>
</body>
</html>

)=====";
//--------------------------------------------------------
// graphic - the HTML code for the page where 
// the wind data is displayed graphically
// located in PROGMEM, as it is going to be static
//--------------------------------------------------------

// MANY THANKS TO https://ziegenhagel.com FOR WRITING THE CODE

const char graphic[] PROGMEM = R"=====(
<div class="pos_upper_right">
    <a href="/config">Einstellungen</a>
</div>
<div id="instrument" class="layer">
    <div id="wind_direction" class="layer">--- deg</div>
    <div id="wind_speed" class="layer">--- m/s</div>
    <div id="nesw" style="margin-top:-5px">
        <div class="layer" style="transform:rotate(0deg)">0</div>
        <div class="layer" style="transform:rotate(90deg)">90</div>
        <div class="layer" style="transform:rotate(180deg)"><div style="transform:rotate(180deg);">180</div></div>
        <div class="layer" style="transform:rotate(270deg)">270</div>
    </div>
    <div id="degs"> </div>
    <div id="pointer" class="layer"><div id="needle"></div></div>
    <div id="dot_on_needle" class="layer"></div>
    <div id="reflection" style="background: linear-gradient(#2223, #2220); height: 140%; width: 200%; margin-left: -50%; margin-top: 41%; opacity: 0.5; " class="layer"></div>
</div>
<script>
    // version 0.3
    // config, change to your needs
    const API_URL = "/data"
    const API_ENABLED = true
    const API_REFRESH_MS = 1000
    // code, don't touch
    let el_pointer = document.getElementById("pointer")
    let el_direction = document.getElementById("wind_direction")
    let el_speed = document.getElementById("wind_speed")
    let degs = document.getElementById("degs")
    var el, rot;
    function refresh_gui(data) {
        rotateThis(el_pointer, data[1])
        el_direction.innerHTML = data[1]+"&deg;"
        el_speed.innerHTML = ((parseFloat(data[3]) * unit_manipulation
    }

    function rotateThis(element, nR) {
    var aR;
    rot = rot || 0; // if rot undefined or 0, make 0, else rot
    aR = rot % 360;
    if ( aR < 0 ) { aR += 360; }
    if ( aR < 180 && (nR > (aR + 180)) ) { rot -= 360; }
    if ( aR >= 180 && (nR <= (aR - 180)) ) { rot += 360; }
    rot += (nR - aR);
    element.style.transform = ("rotate( " + rot + "deg )");
}
    
    function build_gui() {
        let color
        for(let i=0;i<360; i+=10) {
            if(i%90 != 0) {
                if(i > 0 && i < 60) color="green"
                else if(i < 360 && i > 300) color="red"
                else color="gray"
                degs.innerHTML += '<div class="layer" style="transform:rotate('+i+'deg);"><span style="background-color:'+color+';"></span></div>' 
            }
        }
    }
    function refresh_data() {
        fetch(API_URL)
        .then((data) => data.text())
        .then((data) => {
            console.log("API response:",data)
            refresh_gui(data.split(","))
        })
        .catch((error) => {
            console.error("Error:", error)
        })
    }
    build_gui()
    if(API_ENABLED)
        setInterval(refresh_data,API_REFRESH_MS)
    else
        refresh_gui("$WIMWV,250.5,R,1.8,M,A*38".split(","))
</script>
<style>
    body {
        display:flex;
        justify-content:center;
        align-items:center;
        background:#222;
    }
    #degs {
        margin-top:5px;
    }
    #degs > div {
        padding-top:0px;
        color:#fff2;
        font-weight:bold;
    }
    #degs > div > span {
        height:21px;
        width:10px;
        display:inline-block;
    }
    #nesw > div {
        padding-top:11px;
        color:#ccc;
    }
    #instrument {
        position:relative;
        background:linear-gradient(#222,#555);
        border:6px solid gray;
    }
    .layer {
        font-size:30px;
        text-align:center;
        width:400px;
        height:400px;
        position:absolute;
        border-radius:50%;
    }
    #pointer {
        transition:1s;
    }
    #needle {
        background:linear-gradient(#d00,#a00);
        width:9px;
        height:32%;
        border-radius:4px;
        margin:auto;
        margin-top:-6%;
        box-shadow:5px 5px 8px #333;
    }
    #dot_on_needle {
        border-radius:50%;
        width:40px;height:40px;
        margin:-20px;
        left:50%;
        top:50%;
        background:#555;
        box-shadow:2px 2px 3px #1113, inset -3px -3px 10px #0005, inset 3px 3px 10px #fff3;
    }
    #wind_speed, #wind_direction {
        font-family:arial;
        background: #B1BAA9;
        padding:10px;
        height:auto;
        width:110px;
        left:50%;
        margin-left:-65px;
        top:23%;
        box-shadow: inset 2px 2px 3px #0007, inset -2px -2px 3px #fff3;
        border-radius:2px;
    }
    #wind_speed {
        top:63%;
        margin-top:10px;
    } .pos_upper_right {
        padding:10px;
        position:absolute;
        right:0;
        top:0;
    } .pos_upper_right a {
        color:gray;
        font-family:arial;
        text-decoration:none;
    } .pos_upper_right a:hover {
        color:white;
        text-decoration:underline;
    }
   </style>
)=====";


//******************************************************************************************************************************************************
// Support functions for the core code and calculation of data and NMEA0813
//******************************************************************************************************************************************************

//--------------------------------------------------------
// ip_blink - Blinks the IP address of the ESP with the build
// in LED, so you can connect to it without having to scan
// the network or connecting via serial.
// Syntax: It blinks ever digit seperatly, and, in order to
// display the 0, it blinks n+1 times. The dot is indicated
// by three rapid flashes.
// Example: "192." will be displayed as:
// 2 FLASHES, BREAK, 10 FLASHES, BREAK, 3 FLASHES, 3 RAPID FLASHES
//--------------------------------------------------------

void ip_blink() {
  String ip = WiFi.localIP().toString();  //sore current IP in string
  for (int i = 0; i <= ip.length(); i++) {  //for the length of the IP
    if (ip.charAt(i) == '.') {  //check for dots and indicate them by three rapid flashes
      for (int i = 0; i <= 2; i++) {
        digitalWrite(LED, LOW);   //turn the LED on (HIGH is the voltage level)
        delay(100);                       //wait for a second
        digitalWrite(LED, HIGH);   //turn the LED on (HIGH is the voltage level)
        delay(100);                       //wait for a second
      }
    }
    else {
      int times_blink = ip.charAt(i) - '0';  //store the digit at the current position as int
      //    Serial.print(times);
      for (int j = 0; j <= times_blink; j++) {
        digitalWrite(LED, LOW);   //turn the LED on (HIGH is the voltage level)
        delay(200);                       //wait for a second
        digitalWrite(LED, HIGH);    //turn the LED off by making the voltage LOW
        delay(200);
      }
    }
    delay(1000);
  }
}


//--------------------------------------------------------
// nmea_checksum - create NMEA 0183checksum
// Expecting NMEA string that begins with '$' and ends with '*'
// like $WIMWV,152,R,5.4,M,A*
//--------------------------------------------------------

String checksum(char* CSSentence) {
  int cs = 0; //stores the generated dezimal-checksum
  char f[30] = "0";  //stores the final hex-checksum
  for (int n = 0; n < strlen(CSSentence); n++) {
    cs ^= CSSentence[n]; //calculates the checksum
  }
  sprintf(f, "%02X", cs);  //convert the checksum into hex
  return f;
}


//--------------------------------------------------------
// WinSensInterupt - measure the time between the inerrupts
// As this function runs whenever an interrupt is triggered,
// it needs to have the "ICACHE_RAM_ATTR" at its beginning,
// so it can run in RAM
//--------------------------------------------------------

ICACHE_RAM_ATTR void WinSensInterupt() {
  digitalWrite(LED, HIGH);
  if ((millis() - oldtimes) > 50) {  //debounce the signal
    times = millis() - oldtimes;  //get time delta
    oldtimes = millis();  //set oldtimes to current time
  }
  digitalWrite(LED, LOW);
}


//--------------------------------------------------------
// Function: convertRawAngleToDegrees
// In: angle data from AMS_5600::getRawAngle
// Out: human readable degrees as float
// Description: takes the raw angle and calculates
// float value in degrees.
//--------------------------------------------------------

float convertRawAngleToDegrees(word newAngle) {
  /* Raw data reports 0 - 4095 segments, which is 0.087 of a degree */
  float retVal = newAngle * 0.087;
  int ang = retVal;
  return ang;
}


//******************************************************************************************************************************************************
// Support functions for the HTTP-webserver and the correction-values
//******************************************************************************************************************************************************
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
void loop() {
  ArduinoOTA.handle(); //deals with the ArduinoOTA-stuff, must be kept in to preserve posibility of OTA-FW-updates

  webserver.handleClient();  //Handle client requests of the HTTP-webserver

  #ifdef ESP32
  #else 
    MDNS.update();  //Allow mDNS processing
  #endif

  Z = fmod((convertRawAngleToDegrees(ams5600.getRawAngle()) + offset.toInt() + 360), 360); //stores the value of the angle mod 360
//  Z = fmod((convertRawAngleToDegrees(random(260)) + offset.toInt() + 360), 360); //stores the value of the angle mod 360

  byte bySpeedCorrection = 100;  //value for finetuning the speed calculation
  if(times != 0) {  //avoid division by zero
  WS = (((33 * bySpeedCorrection) / (times))*factor.toFloat());  //calculating the wind speed
  }

  
  //--------------------------------------------------------
  // Assembly of the NMEA0183-sentence to calculate the checksum
  // Beware: sprintf works on raw storage. If the chars
  // are not initialized long enough, it will cause an
  // buffer overflow
  //--------------------------------------------------------

  strcpy(MWVSentence, "WIMWV,");
  sprintf(e, "%d", Z); //e represents the angle in degrees
  strcat(MWVSentence, e);
  strcat(MWVSentence, ",R,");
  sprintf(d, "%d", WS / 10); //d represent the meters/seconds
  sprintf(c, ".%d", (WS % 10)); //c represent the decimal
  strcat(MWVSentence, d);
  strcat(MWVSentence, c);
  strcat(MWVSentence, ",M,A");


  //--------------------------------------------------------
  // Assembly and sending of the NMEA0183-sentence via TCP
  //--------------------------------------------------------
  
  if (server.hasClient()) {  //only send if there are clients to receive
    for (int i = 0; i < MAX_CLIENTS; i++) {

      //added check for clients[i].status==0 to reuse connections
      if ( !(clients[i] && clients[i].connected() ) ) {
        if (clients[i]) {
          clients[i].stop(); // make room for new connection
        }
        clients[i] = server.available();
        continue;
      }
    }

    // No free spot or exceeded MAX_CLENTS so reject incoming connection
    server.available().stop();
  }

  checksum(MWVSentence).toCharArray(g, 85); //calculate checksum and store it

  //final assembly of the TCP-message to be send
  strcpy(result, "$");  //start with the dollar symbol
  strcat(result, MWVSentence); //append the MWVSentence
  strcat(result, "*"); //star-seperator for the CS
  strcat(result, g);  //append the CS

  // Broadcast NMEA0183 sentence to all clients
  for (int i = 0; i < MAX_CLIENTS; i++) {
    if (clients[i] && clients[i].connected()) {
      clients[i].println(result);  //make sure to use println and not write, at least it did not work for me
    }
  }
  #ifdef ESP32
    if(nmea2k.equals("NMEA2000-Daten werden erstellt und ausgegeben <input type=\"button\" onclick=\"location.href='/nmea2k';\" value=\"Ändern\" /> <br>  <br>")) {  //only call the NMEA2000-functions if settings say so
      //--------------------------------------------------------
      // Assembly and sending of the NMEA2000-sentence via CAN
      //--------------------------------------------------------
      tN2kMsg N2kMsg;  //get local instance of N2KMsg
      SetN2kWindSpeed(N2kMsg, 1, WS, DegToRad(Z),N2kWind_Apprent);  //create the datagram with the current values of WS (windspeed) and Z (angle in degrees)
      NMEA2000.SendMsg(N2kMsg);  //send out the message via the CAN BUS
 
      NMEA2000.ParseMessages();

      CheckSourceAddressChange();
  
      if ( Serial.available() ) {  //Dummy to empty input buffer to avoid board to stuck with e.g. NMEA Reader
        Serial.read();
      }
    }
  #endif

  //--------------------------------------------------------
  // Sending of the NMEA0183-sentence via SERIAL
  //--------------------------------------------------------
  Serial.print(result);
  Serial.print("\r");
  Serial.print("\n");
  Serial.println();

  // Wait for next reading
  for (int c = 0; c < DELAY_COUNT; c++) {
    delay(DELAY_MS);
  }

}

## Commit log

2021-06-22 webserver added
    There now is a HTTP-webserver at port 80 where correction-values can be applied and the blinking of the IP can be enabled/disabled
    [1.0.ino]
2021-06-23 HTTP-webserver and mDNS added
    An HTTP-webserver on port 80 was added. There, correction values can be applied. The ESP can now be reached at windsensor.local from within the own network.
    NOTE: This does not work on Android devices.
    Also, the blinking of the IP can be turned on and of via a button on the webserver
    [1.1.ino]
2021-06-24 Demo to test the firmware without the sensors
    randomly creates values for the angle and the wind speed.
2021-06-30 Updated demo.ino to version 1.2
    GUI for displaying the wind data added
    minor bug fixes
    [demo.ino]
2021-06-30 Updated to version 1.2
    graphic display of the wind data added
    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
    [1.2.ino]
2021-06-30 Update demo.ino to version 1.2
    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
    [demo.ino]
2021-06-30 Update 1.2.ino
    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
    [1.2.ino]
2021-07-03 Create stl
2021-07-03 STL files
    all STL-files required to print the Windsensor
    [Fuß.stl, Gehäuse_hinten.stl, Gehäuse_vorn.stl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]
2021-07-28 unit of the wind speed in the GUI can be changed
    only affects GUI and not the send NMEA0813, km/h, m/s or knots can be selected
2021-07-28 BIN of version 1.4 added
    the unit of the wind speed in the GUI can now be changed between m/s, km/h and knots
2021-08-16 Gerber Files added
    [Windsensor III_copper_bottom.gbr, Windsensor III_copper_top.gbr, Windsensor III_outline.gbr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]
